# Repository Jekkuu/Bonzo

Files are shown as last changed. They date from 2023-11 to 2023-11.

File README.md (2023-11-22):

Todo: 1. modify screw holes to use only one lenght of screw
      2. make screw holes cleaner to print

# Bonzo
## Pro Micro based custom pseudo 40% keyboard inspired by [V4N4G0N](https://trashman.wiki/keyboards/v4n4g0n)

Bonzo

## Kicad libraries used:

https://github.com/AcheronProject/AlexandriaLibrary
https://github.com/keebio/Keebio-Parts.pretty
https://github.com/ai03-2725/MX_Alps_Hybrid/tree/master/MX_Only.pretty

## Gerbers

The provided gerbers have been created according to the specifications of JLCpcb. For plate the size is 275.3mm * 113.4mm

## Cases 

### Acryllic case

The case is designed to be cut out of 3mm acryllic and uses a 1.5mm switchplate.

I used 4mm female to female M2 standoffs from this listing: https://www.aliexpress.com/item/1005003106030065.html

https://i.imgur.com/W8KVRhH.png Picture for reference if the listing gets deleted

### 3D printable case WIP

This case has been printed fully and works, but the screwholes are too tight and have to be drilled.

Updated case design with heat insrets and correct size holes at some point.

## Firmware 

I have provided a compiled .hex and a layout json that will let you use the keyboard with VIA.

The full QMK library is also provided incase it is needed.

## BOM

### General parts for wired

| Name | Pieces | Description |
| --- | --- | --- |
| PCB | 1 | Gerbers available at this repository |
| 1,5mm switch plate | 1 | Gerbers available at this repository |
| 2U PCB mount stabilizer | 3 | Also known as screw-in stabilizers |
| MX hotswap sockets | 54 | Kailh or equivalent |
| MX style switch | 54 | |
| 1N4148 diodes | 54 | SOD-123 packaging |
| ProMicro or similar | 1 | |

### For Wireless

| Name | Pieces | Description |
| --- | --- | --- |
| PCB | 1 | Gerbers available at this repository |
| 1,5mm switch plate | 1 | Gerbers available at this repository |
| 2U PCB mount stabilizer | 3 | |
| MX hotswap sockets | 54 | Kailh or equivalent |
| MX style switch | 54 | |
| 1N4148 diodes | 54 | SOD-123 packaging |
| nice!nano v2 | 1 | |
| LiPo battery | 1 | Refer to [nice!nano's documentation](https://nicekeyboards.com/docs/nice-nano/) on battery suggestions |
| Slide switch | 1 | JS202011AQN or similar |

#### For acryllic case

| Name | Pieces | Description |
| --- | --- | --- |
| Acrylic layers | 1 of each | Files available in this repository |
| 4-6mm M2 female - female standoffs | 8 | Hexagon shaped ones won't fit |
| M2 screws | 16 | |

#### For 3DP case

| Name | Pieces | Description |
| --- | --- | --- |
| Top case | 1 | |
| Bottom case  | 1 | |
| M2x15 screws | 4 | Self-tapping screws are recommended |
| M2x10 screws | 4 | Self-tapping screws are recommended |

## Keycaps
You will also need keycaps to fit the layout pictured below 
layout

# Disclaimer
**Everything in this repo has been published with intent to allow others to build this keyboard if they want to and is published under MIT License. The versions I have uploaded have been tested to work. I take no responsibility of designs being incorrect or flawed. Check all the files yourself before you purchase anything. If something is broken or missing please let me know and ill try and see if I can fix the issue.**

Also here is the cat who inspired the name and the silkscreen
The boy

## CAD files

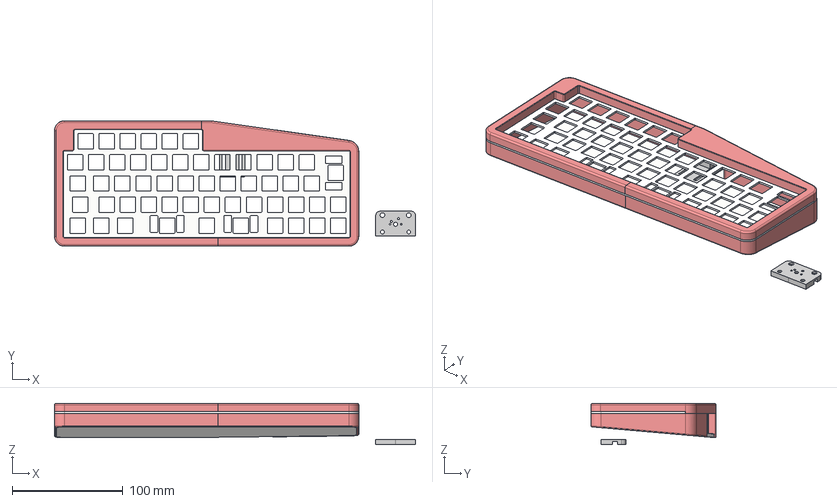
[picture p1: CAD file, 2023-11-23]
3DP Case With Acrylic backplate and handwire support/bonzo 3d print handwire with acrylic backplate.step
326.6 x 113.5 x 37.4 mm

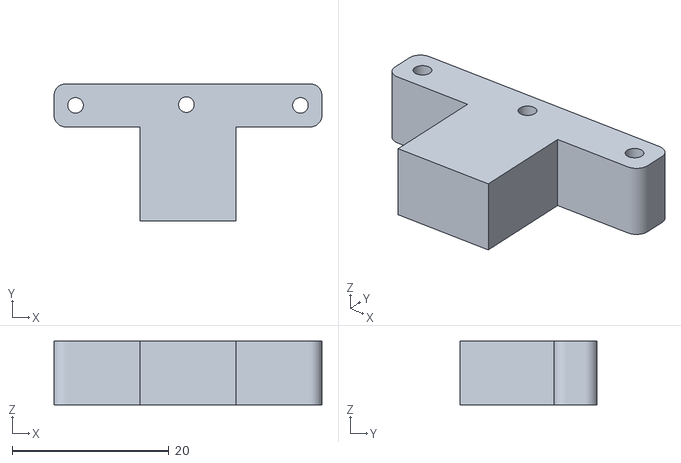
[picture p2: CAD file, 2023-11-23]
3DP Case With Acrylic backplate and handwire support/promicro spacer.stl
34.2 x 17.5 x 8.14

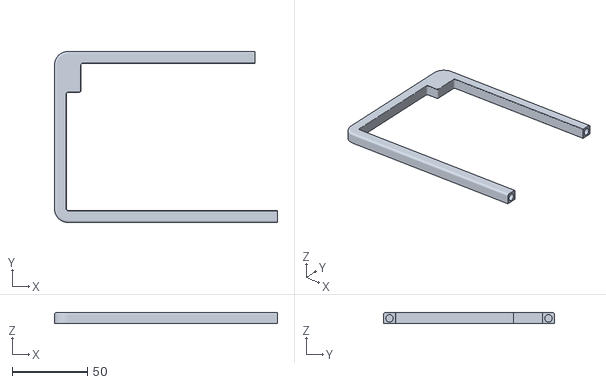
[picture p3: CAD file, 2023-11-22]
3DP Case With Acrylic backplate and handwire support/top left.stl
147.8 x 113.4 x 7.50

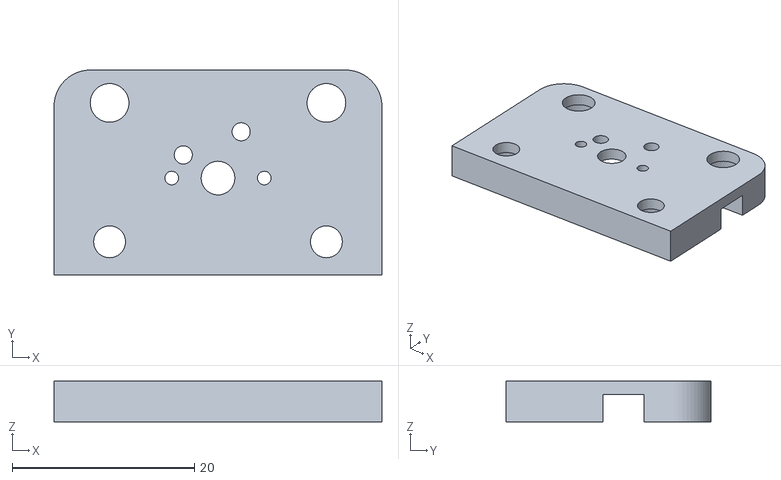
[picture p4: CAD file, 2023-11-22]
3DP Case With Acrylic backplate and handwire support/stab holder.stl
36.0 x 22.5 x 4.50

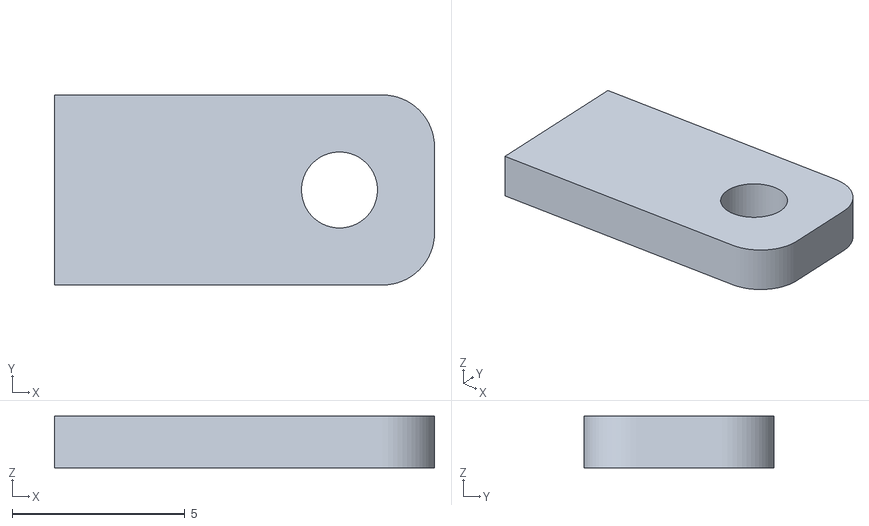
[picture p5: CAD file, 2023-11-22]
3DP Case With Acrylic backplate and handwire support/promicro lock.stl
11.0 x 5.50 x 1.50

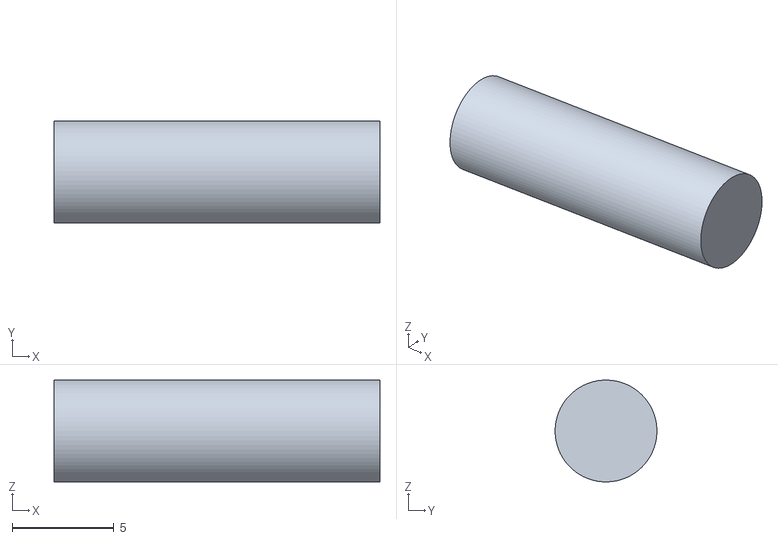
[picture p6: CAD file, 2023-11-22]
3DP Case With Acrylic backplate and handwire support/connecting rod.stl
16.0 x 5.00 x 5.00

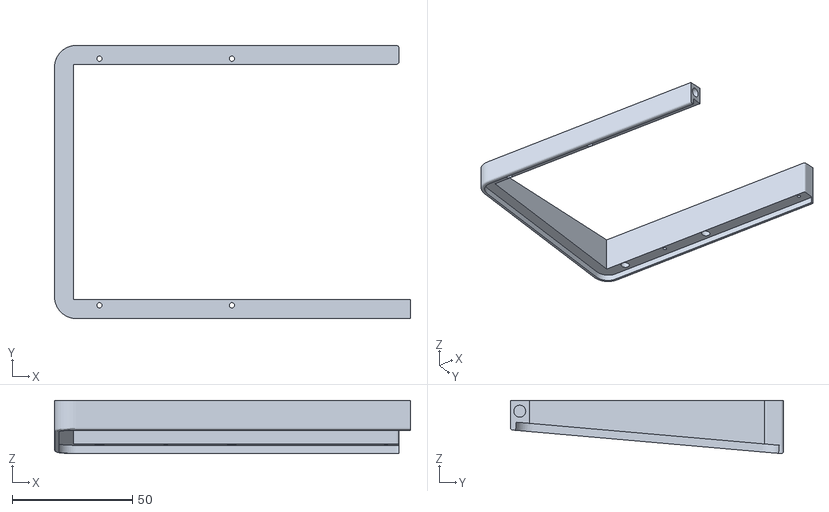
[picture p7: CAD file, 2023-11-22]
3DP Case With Acrylic backplate and handwire support/bottom left.stl
147.8 x 113.4 x 22.1

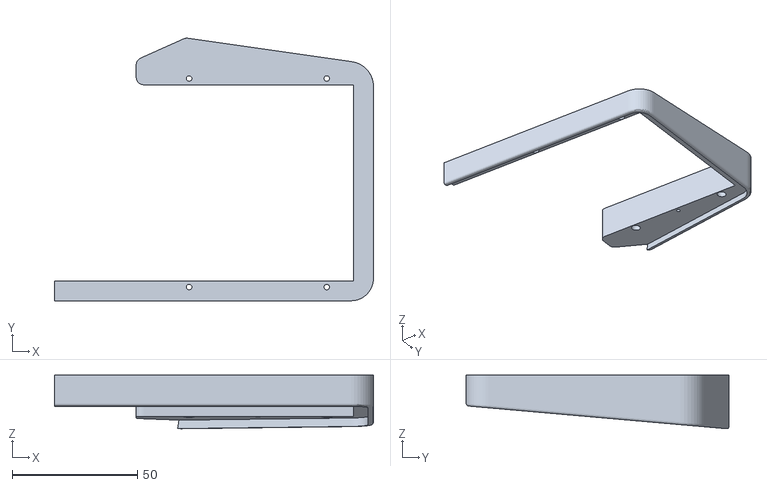
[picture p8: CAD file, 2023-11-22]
3DP Case With Acrylic backplate and handwire support/bottom right.stl
127.5 x 105.0 x 21.4

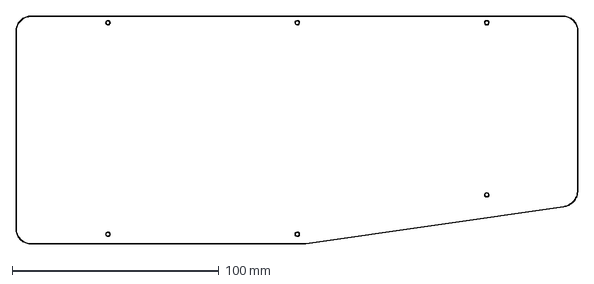
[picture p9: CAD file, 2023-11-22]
3DP Case With Acrylic backplate and handwire support/acrylic backplate.dxf
271.3 x 109.8 mm

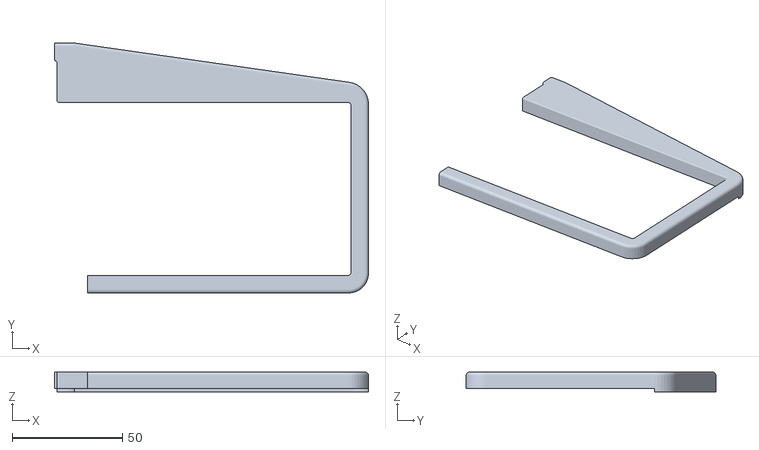
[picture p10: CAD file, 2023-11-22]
3DP Case With Acrylic backplate and handwire support/top right.stl
142.5 x 113.4 x 9.00

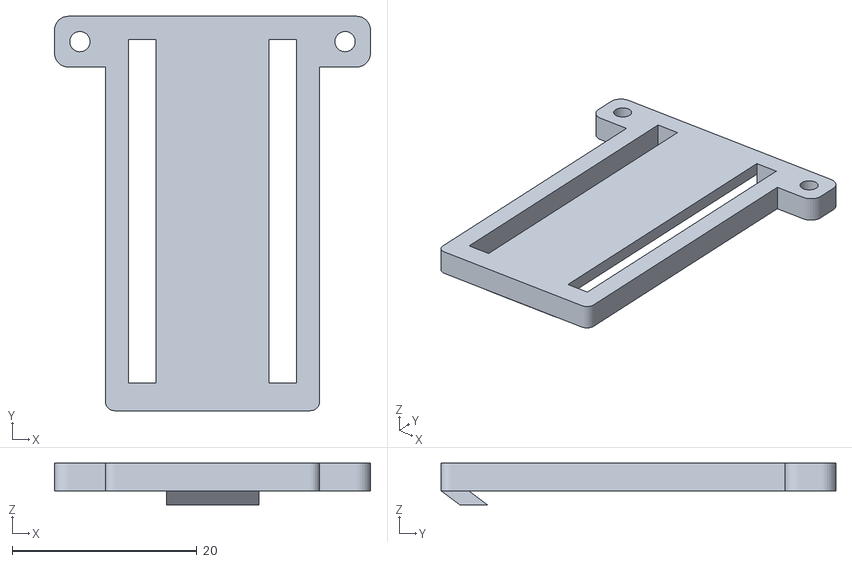
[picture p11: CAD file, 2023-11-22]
3DP Case With Acrylic backplate and handwire support/promicro mount.stl
34.2 x 42.7 x 4.50

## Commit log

2023-11-22 add files for handwire version of bonzov2
    [acrylic backplate.dxf, bonzo 3d print handwire with acrylic backplate.step, bottom left.stl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]
2023-11-23 made promicro spacer holes a little tighter
    [bonzo 3d print handwire with acrylic backplate.step, promicro spacer.stl]
